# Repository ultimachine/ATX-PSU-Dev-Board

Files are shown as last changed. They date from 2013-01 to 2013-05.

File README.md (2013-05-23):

##About
This is an ATX breakout board inspired and based on <http://www.sparkfun.com/products/9558>.

##Purchasing
The board can be purchased from UltiMachine.com in PCB-only, DIY-kit, or assembled form at <https://ultimachine.com/content/atx-psu-dev-board>.

##License
This work is licensed under the [Creative Commons Attribution-ShareAlike 3.0 United States License](http://creativecommons.org/licenses/by-sa/3.0/us/).

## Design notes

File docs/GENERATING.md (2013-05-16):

#Note
This documentation procedure is very rough and still in development. The goal of the documentation for the ATX PSU Dev Board was to experiment with reducing the amount of time required for documenting in multiple places. For this project a shell script was used to quickly prototype the workflow. It is far from an ideal solution, but has given us ideas for future implementations. 

#Triple Documentation Workflow
The main content is written in markdown. A title page for the PDF is created in LaTeX. The photos are edited in GIMP. ImageMagick and xcf2png are used to convert the GIMP files to png and scale them. We use pandoc to convert the markdown to mediawiki for reprap.org (and other websites). Next the markdown is converted to LaTeX and appended to the title page. We generate a PDF from the LaTeX. All of this is performed with the build.sh script.

#Contributing
Modifications to the documentation happen in the following files/folders.

- build.sh (Build script)
- user-manual.md (Human generated instructions)
- user-manual.tex (The title page for the PDF, includes the LaTeX output from pandoc)
- /xcf (All the pictures editable in GIMP)

Everything else is generated by a piece of software and is recreated each build (for now, however an ideal solution would be like a makefile). 

##Markdown Syntax
<http://daringfireball.net/projects/markdown/syntax>

#Required Programs to run build.sh

- ImageMagick
- xcf2png
- pandoc
- pdflatex

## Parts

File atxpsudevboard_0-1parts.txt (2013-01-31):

Partlist

Exported from atxpsudevboard_0-1.sch at 1/9/2012 9:30:20 AM

EAGLE Version 6.0.0 Copyright (c) 1988-2011 CadSoft

Assembly variant: 

Part     Value /Newark No.  Device             Package           Library         Sheet

F1       5A   16F1791       PTCFUSEMFR1100     MFR1100           RepRapjr        1
F2       11A  60H8377       PTCFUSEMFR1100     MFR1100           RepRapjr        1
F3       5A   16F1791       PTCFUSEMFR1100     MFR1100           RepRapjr        1
F4       5A   16F1791       PTCFUSEMFR1100     MFR1100           RepRapjr        1
F5       5A   16F1791       PTCFUSEMFR1100     MFR1100           RepRapjr        1
H5       MOUNT-PAD-ROUND3.0 MOUNT-PAD-ROUND3.0 3,0-PAD           holes           1
H6       MOUNT-PAD-ROUND3.0 MOUNT-PAD-ROUND3.0 3,0-PAD           holes           1
H7       MOUNT-PAD-ROUND3.0 MOUNT-PAD-ROUND3.0 3,0-PAD           holes           1
H8       MOUNT-PAD-ROUND3.0 MOUNT-PAD-ROUND3.0 3,0-PAD           holes           1
J1       ATX24RH            ATX24RH            ATX24_RIGHT_ANGLE SparkFun        1
JP1                         PINHD-1X2          1X02              pinhead         1
JP2                         M06LONGPADS        1X06_LONGPADS     SparkFun        1
LED1                        LED3MM             LED3MM            led             1
LED2                        LED3MM             LED3MM            led             1
R1       30R (5W) 16R2247   RHPS923            HPS923            resistor-power  1
R2       22R (3W) 74M3349   RCA4050            CA4050            resistor-power  1
R3       1K                 R-US_0207/7        0207/7            resistor        1
R4       1K                 R-US_0207/7        0207/7            resistor        1
X2       MSTBA10            MSTBA10            MSTBA10           con-phoenix-508 1
         MSTBA pluggables for each

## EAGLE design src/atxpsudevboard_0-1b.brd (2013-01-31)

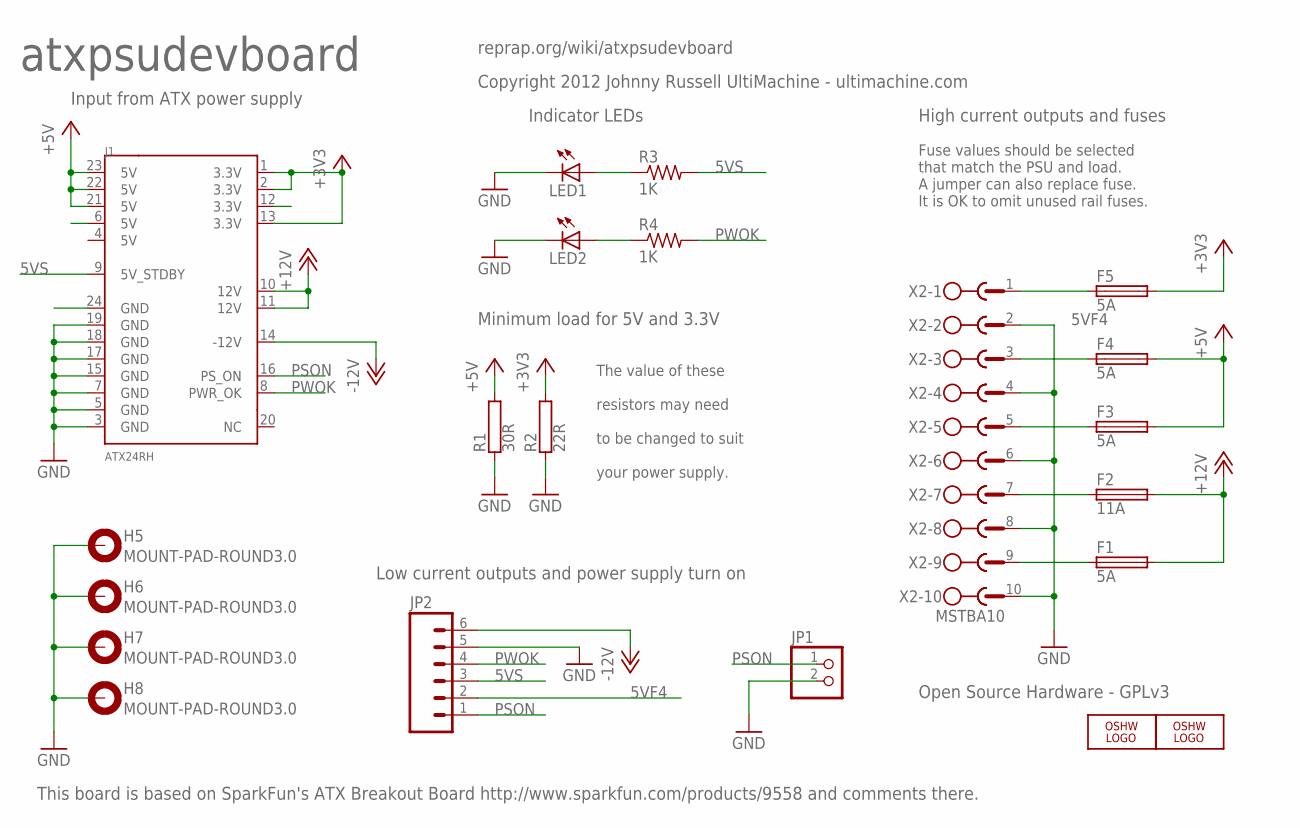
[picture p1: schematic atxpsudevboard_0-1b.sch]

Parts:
F1, F3, F4, F5: 5A; MFR1100
F2: 11A; MFR1100
H5, H6, H7, H8: MOUNT-PAD-ROUND3.0; 3,0-PAD
J1: ATX24RH; ATX24_RIGHT_ANGLE
JP1: PINHD-1X2; 1X02
JP2: M06LONGPADS; 1X06_LONGPADS
LED1, LED2: LED3MM
LOGO1: OSHW_LOGO_FILLX0100-NT; OSHW_FILLX100_NOTEXT
LOGO2: OSHW_LOGO_FILLX0200-NT; OSHW_FILLX200_NOTEXT
R1: 30R; HPS923
R2: 22R; CA4050
R3, R4: 1K; 0207/7
X2: MSTBA10

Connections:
5VF4: F4.1, JP2.2, X2.3
5VS: J1.9 (5V_STDBY), JP2.3, R3.2
+3V3: F5.2, J1.1 (3.3V), J1.2 (3.3V), J1.13 (3.3V), R2.2
+5V: F3.2, F4.2, J1.21 (5V), J1.22 (5V), J1.23 (5V), R1.2
+12V: F1.2, F2.2, J1.10 (12V), J1.11 (12V)
-12V: J1.14 (-12V), JP2.6
GND: H5.B3,0, H6.B3,0, H7.B3,0, H8.B3,0, J1.3 (GND), J1.5 (GND), J1.7 (GND), J1.15 (GND), J1.17 (GND), J1.18 (GND), J1.19 (GND), JP1.2, JP2.5, LED1.K (C), LED2.K (C), R1.1, R2.1, X2.2, X2.4, X2.6, X2.8, X2.10
unnamed: F2.1, X2.7
unnamed: F1.1, X2.9
unnamed: F3.1, X2.5
unnamed: F5.1, X2.1
unnamed: LED1.A, R3.1
unnamed: LED2.A, R4.1
PSON: J1.16 (PS_ON), JP1.1, JP2.1
PWOK: J1.8 (PWR_OK), JP2.4, R4.2

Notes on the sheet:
atxpsudevboard
Input from ATX power supply
Indicator LEDs
Minimum load for 5V and 3.3V
to be changed to suit
your power supply.
The value of these
resistors may need
Low current outputs and power supply turn on
High current outputs and fuses
Copyright 2012 Johnny Russell UltiMachine - ultimachine.com
reprap.org/wiki/atxpsudevboard
Open Source Hardware - GPLv3
This board is based on SparkFun's ATX Breakout Board http://www.sparkfun.com/products/9558 and comments there.
Fuse values should be selected
that match the PSU and load.
A jumper can also replace fuse.
It is OK to omit unused rail fuses.

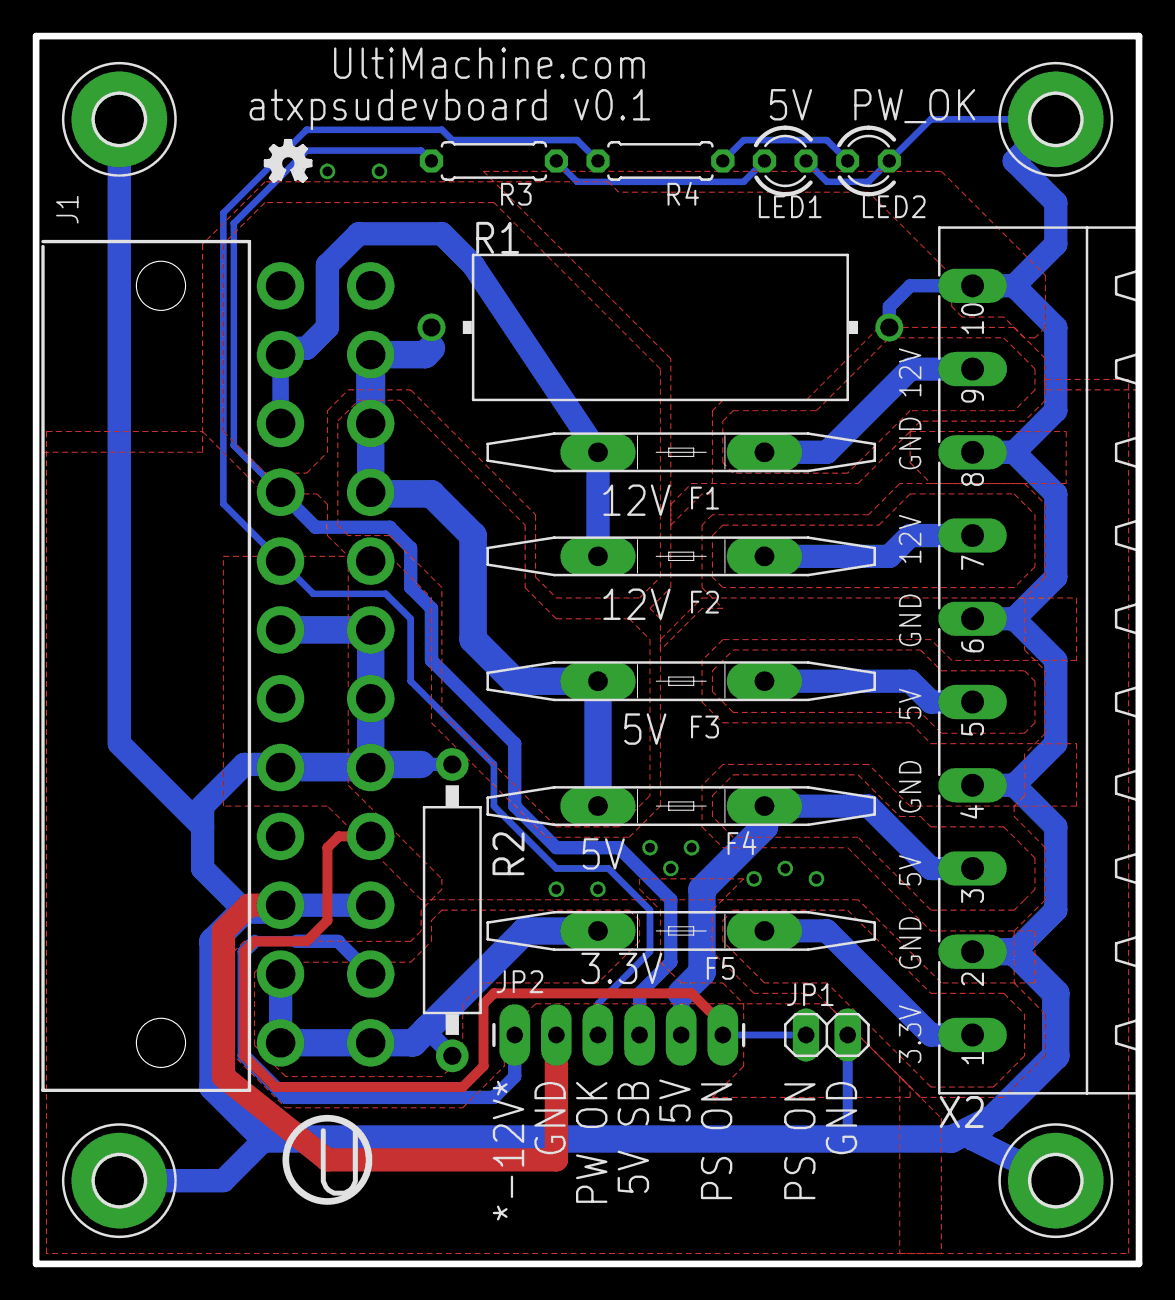
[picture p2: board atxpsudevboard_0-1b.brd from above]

Board: 2 copper layers, 67.3 x 74.9 mm, 21 parts (0 on the bottom side), 15 nets.

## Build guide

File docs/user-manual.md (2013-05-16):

#Introduction

##What's in the box
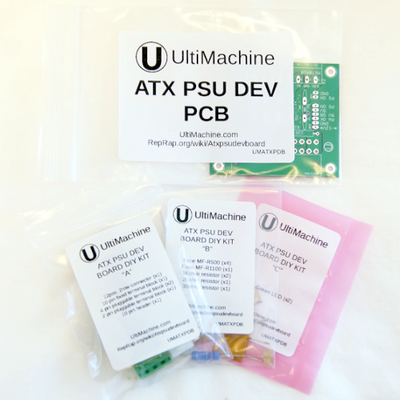
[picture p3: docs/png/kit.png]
Bag Layout


#Preparation

##Tools
The following tools and materials are required to assemble the ATX PSU Dev Board:

- Soldering Iron
- Solder
- Flush/diagonal cutters

Additional tools that might be helpful, but not required:

- Lead bender (some 3D printable ones can be found online)

##Soldering
If you do not have prior experience soldering, we recommend checking out a few of the following websites for tutorials.

- <http://mightyohm.com/files/soldercomic/FullSolderComic_EN.pdf>
- <http://www.ladyada.net/media/common/soldering.pdf>
- <http://store.curiousinventor.com/guides/How_to_Solder>
- <http://www.sparkfun.com/tutorials/106>
- <http://radiojove.gsfc.nasa.gov/telescope/soldering.htm>

#Assembly

##Board Orientation
The components of this board will be inserted on the side with the outlines.

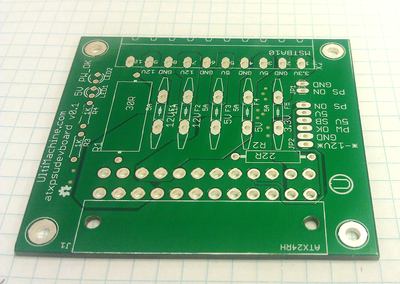
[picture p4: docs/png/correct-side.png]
Correct Side
 

##Step 1
Begin by inserting the two 1k ohm [resistors](http://en.wikipedia.org/wiki/Resistors) and the [LEDs](http://en.wikipedia.org/wiki/LED) into the board. The LEDs should have the longest lead in the hole facing the resistor. If they are inserted incorrectly they will not work. This is because they are diodes. Diodes only allow current to flow in one direction. Resistors are not [polarized](http://en.wikipedia.org/wiki/Electrical_polarity) components, so they can be inserted in orientation.

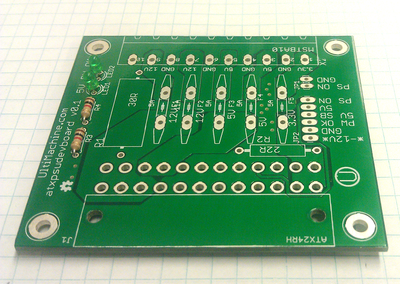
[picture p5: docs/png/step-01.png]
Step 1


##Step 2
Next flip over the board and solder the components in. You may need to slightly bend the leads to prevent the componets from falling out of the board. 

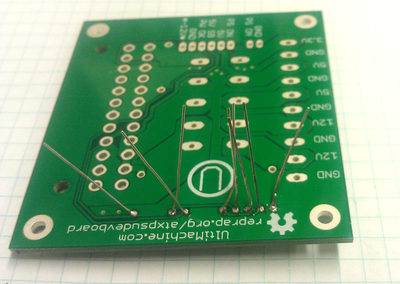
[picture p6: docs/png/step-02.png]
Step 2


##Step 3
Now that the components are soldered in and secure, you can cut the leads.

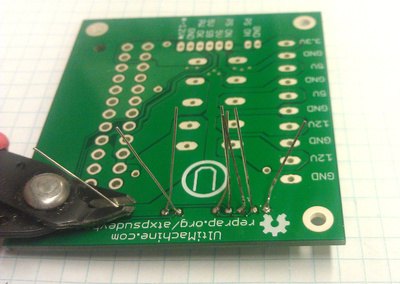
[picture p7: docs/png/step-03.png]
Step 3


##Step 4
The [fuses](http://en.wikipedia.org/wiki/Fuse_%28electrical%29) will be inserted next. They have a coating that slightly descends down the leads as shown below.

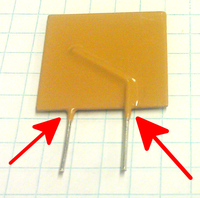
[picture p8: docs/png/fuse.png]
Resetable Fuse


In order to make a good connection the fuses should slightly hover over the holes. This is so the coating on the leads does not interfere with soldering. You want to bring the fuse above the board. This can be done with RepRap filament or something else, such as a long screw. The orientation of the fuses does not matter. 

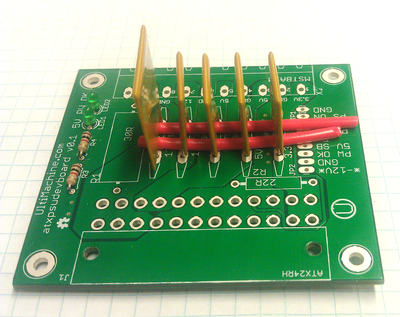
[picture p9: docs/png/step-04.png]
Step 4


##Step 5
You will need to remove the filament before continuing. 

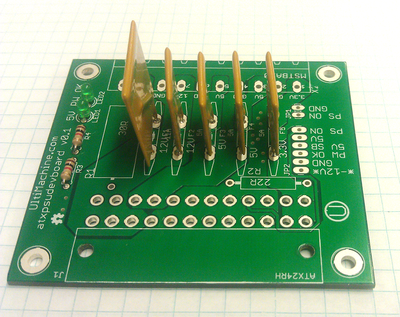
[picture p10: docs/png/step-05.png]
Step 5


Now is a good opportunity to inspect the solder joints. Since the connectors and fuses on this board might carry as much as 10 amps you want a good solder connection. You can check the quality of the solder joint by looking at the other side of the leads. A good connection is shown on the left lead, with a potentially weak one on the right lead. Add some [flux](http://en.wikipedia.org/wiki/Flux_%28metallurgy%29) and reheat the joint to touch-up the connections if needed. 

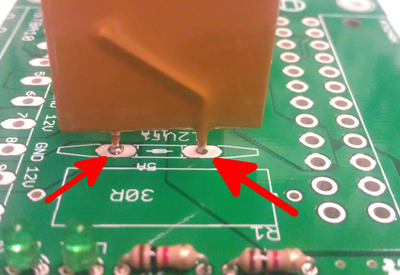
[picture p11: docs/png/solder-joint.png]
Solder Joint


##Step 6
Next you will want to solder in the remaining resistors. Again, orientation does not matter for resistors.

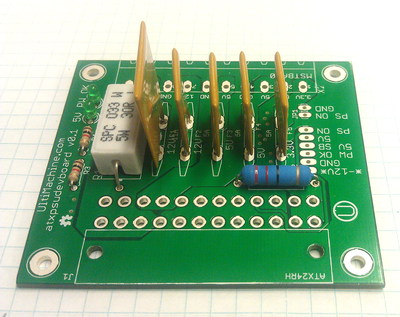
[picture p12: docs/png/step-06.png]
Step 6
 

##Header Pin Preparation
Next locate the header pins in the parts bag. You will need to break them into a strip of 6 and 2 as shown below. This can be done with flush cutters.

Split header pins 

##Step 7
Solder the header pins as shown.

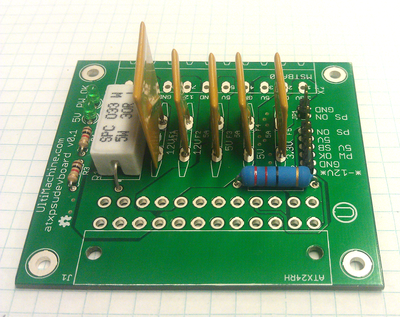
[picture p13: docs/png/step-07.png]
Step 7
 

##Step 8
Add the recieving end for the pluggable headers.

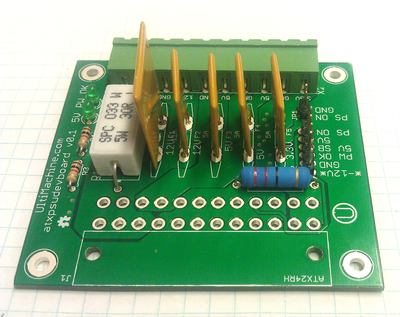
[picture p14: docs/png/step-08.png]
Step 8
 

##Step 9
Next you will want to add the ATX connector. It has barbs on the housing that should clip onto the circuit board. Make sure the connector is well seated before soldering.

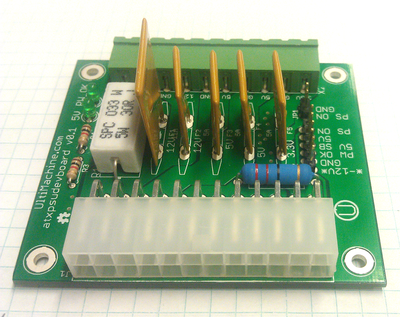
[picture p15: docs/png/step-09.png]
Step 9
 

You have now completed assembly of the ATX PSU Dev Board!
 
#Usage
In order to turn the power supply on, a jumper between "PS ON" and "GND" must be added. Optionally, this can be connected to a micro controller.

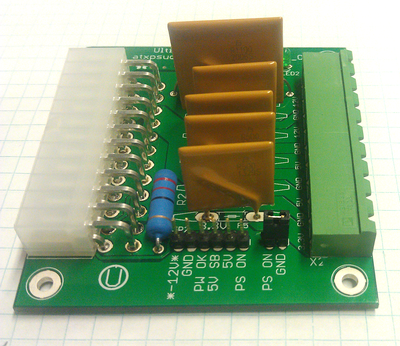
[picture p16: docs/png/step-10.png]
PS_ON Jumper
 

When an ATX power supply is connected to the board and turned on the "PW OK" and "5V" light will turn on. Otherwise if not turned on but connected, just the "5V" light will be on.

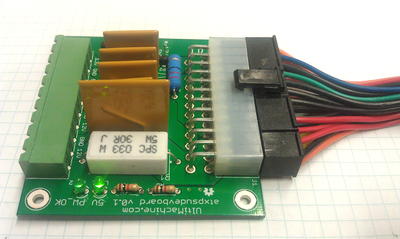
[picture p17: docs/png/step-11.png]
Testing a power supply


Finally you can connect the pluggable headers into the board and power your project!

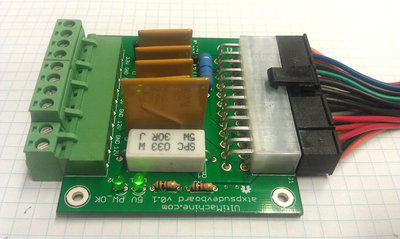
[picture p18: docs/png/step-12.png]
Pluggable headers inserted


#Source
The source for the ATX PSU Dev Board can be found in the UltiMachine repositories on GitHub.com at <https://github.com/ultimachine/ATX-PSU-Dev-Board>.

#Issues
Product support inquiries can be directed to <info@ultimachine.com>.
In the event there is an error in the documentation or problem with the board, please report the issue to the bug tracker at <https://github.com/ultimachine/ATX-PSU-Dev-Board/issues>.

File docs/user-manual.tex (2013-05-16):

\documentclass{article}

\usepackage[pdftex]{geometry}	% Use A4 paper margins
\usepackage[english]{babel}
\usepackage{graphicx}
\usepackage{url}
\usepackage{hyperref}
\usepackage{float}
\usepackage{xcolor} % Required for specifying custom colors
\usepackage{fix-cm} % Allows increasing the font size of specific fonts beyond LaTeX default specifications
\usepackage{tikz}
\usepackage{listings}
\usepackage{pgfplots}
\usepackage{float}
\usepackage{todonotes}
\usepackage{rotating}
\usepackage{pgfplotstable}

\setlength{\oddsidemargin}{0mm} % Adjust margins to center the colored title box
\setlength{\evensidemargin}{0mm} % Margins on even pages - only necessary if adding more content to this template

\newcommand{\HRule}[1]{\hfill \rule{0.2\linewidth}{#1}} % Horizontal rule at the bottom of the page, adjust width here
\renewcommand{\familydefault}{\sfdefault}
\let\ORIincludegraphics\includegraphics
\renewcommand{\includegraphics}[2][]{\ORIincludegraphics[scale=0.7,#1]{#2}}
\begin{document}

\begin{titlepage}

  {\Huge ATX PSU Dev Board }\\
  {\Large Assembly Instructions for v0.1} 
  \vspace*{\fill}	
  \begin{center}
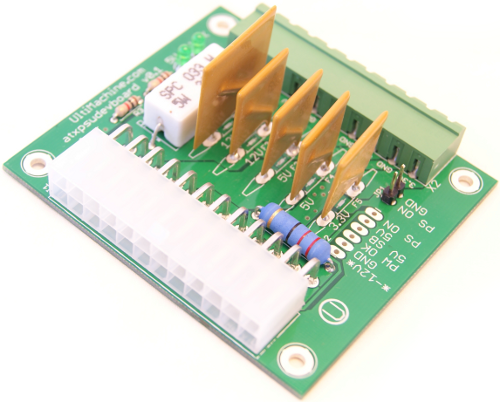
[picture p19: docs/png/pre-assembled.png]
  
  \end{center}
  \vspace*{\fill}

  \vfill
  {\centering \large 
  \hfill  \\
  \hfill \url{http://ultimachine.com/content/atx-psu-dev-board} \\

  \HRule{1pt}} % Horizontal line, thickness changed here
\end{titlepage}

\clearpage % Whitespace to the end of the page

\tableofcontents
\clearpage

\input{./tex/user-manual-body.tex}

\end{document}

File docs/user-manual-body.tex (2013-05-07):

\section{Overview}

\subsection{Introduction}

\subsubsection{What's in the box}

\begin{figure}[htbp]
\centering

\caption{Bag Layout}
\end{figure}

\subsection{Assembly}

\subsubsection{Preparation}

\paragraph{Tools}

The following tools and materials are required to assemble the ATX PSU
Dev Board:

\begin{itemize}
\itemsep1pt\parskip0pt\parsep0pt
\item
  Soldering Iron
\item
  Solder
\item
  Flush/diagonal cutters
\end{itemize}

Additional tools that might be helpful, but not required:

\begin{itemize}
\itemsep1pt\parskip0pt\parsep0pt
\item
  Lead bender (some 3D printable ones can be found online)
\end{itemize}

\paragraph{Soldering}

If you do not have prior experience soldering, we recommend checking out
a few of the following websites for tutorials.

\begin{itemize}
\itemsep1pt\parskip0pt\parsep0pt
\item
  \url{http://mightyohm.com/files/soldercomic/FullSolderComic_EN.pdf}
\item
  \url{http://www.ladyada.net/media/common/soldering.pdf}
\item
  \url{http://store.curiousinventor.com/guides/How_to_Solder}
\item
  \url{http://www.sparkfun.com/tutorials/106}
\item
  \url{http://radiojove.gsfc.nasa.gov/telescope/soldering.htm}
\end{itemize}

\subsubsection{Assembly}

The components of this board will be inserted on the side with the
outlines

\begin{figure}[htbp]
\centering
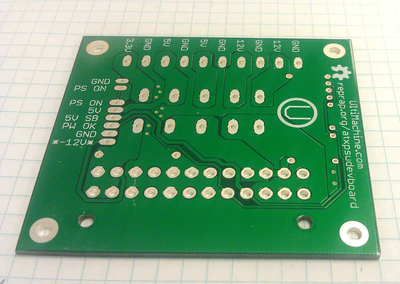
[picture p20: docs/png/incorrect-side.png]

\caption{Incorrect Side}
\end{figure}

Begin by inserting the two 1k ohm resistors and the LEDs into the board.
The LEDs should have the longest lead in the hole facing the resistor.
If they are inserted incorrectly they will not work. This is because
they are diodes. Resistors are not polarized components, so they can be
inserted in orientation.

\begin{figure}[htbp]
\centering

\caption{Step 1}
\end{figure}

Next flip over the board and solder the components in.

\begin{figure}[htbp]
\centering

\caption{Step 2}
\end{figure}

Now that the components are soldered in and secure you can cut the
leads.

\begin{figure}[htbp]
\centering

\caption{Step 3}
\end{figure}

The fuses will be inserted next. They have a coating that slightly
descends down the leads.

\begin{figure}[htbp]
\centering

\caption{Resetable Fuse}
\end{figure}

In order to make a good connection the fuses should slightly hover over
the holes. This is so the coating on the leads does not interfere with
soldering. You want to bring the fuse above the board. This can be done
with RepRap filament or something else, such as a long screw. The
orientation of the fuses does not matter.

\begin{figure}[htbp]
\centering

\caption{Step 4}
\end{figure}

You can remove the filament.

\begin{figure}[htbp]
\centering

\caption{Step 5}
\end{figure}

Now is a good opportunity to check that all connections were soldered
well. Ideally the solder should wick up the lead onto the other side of
the board. It should also have a nice tapered look. Add some flux and
reheat the joint to touch-up the connections if needed. \textbackslash{}

Now is a good opportunity to inspect the solder joints. Since the
connectors and fuses on this board might carry as much as 10 amps you
want a good solder connection. You can check the quality of the solder
joint by looking at the other side of the leads. A good connection is
shown on the left lead, with a potentially weak one on the right lead.

\begin{figure}[htbp]
\centering

\caption{Solder Joint}
\end{figure}

Next you will want to solder in the remaining resistors. Again,
orientation does not matter for resistors.

\begin{figure}[htbp]
\centering

\caption{Step 6}
\end{figure}

Next locate the header pins in the parts bag. You will need to break
them into a strip of 6 and 2 as shown below. This can be done with flush
cutters.

\begin{figure}[htbp]
\centering

\caption{Split header pins}
\end{figure}

Solder the header pins as shown.

\begin{figure}[htbp]
\centering

\caption{Step 7}
\end{figure}

Add the recieving end for the pluggable headers.

\begin{figure}[htbp]
\centering

\caption{Step 8}
\end{figure}

Next you will want to add the ATX connector. It has barbs on the housing
that should clip onto the circuit board. Make sure the connector is well
seated before soldering.

\begin{figure}[htbp]
\centering

\caption{Step 9}
\end{figure}

You have now completed assembly of the ATX PSU Dev Board!

\section{Usage}

\begin{figure}[htbp]
\centering

\caption{PS\_ON Jumper}
\end{figure}

\begin{figure}[htbp]
\centering

\caption{Testing a power supply}
\end{figure}

\begin{figure}[htbp]
\centering

\caption{Pluggable headers inserted}
\end{figure}

\section{Source}

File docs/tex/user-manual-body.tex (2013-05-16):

\section{Introduction}

\subsection{What's in the box}

\begin{figure}[H]
\centering

\caption{Bag Layout}
\end{figure}

\section{Preparation}

\subsection{Tools}

The following tools and materials are required to assemble the ATX PSU
Dev Board:

\begin{itemize}
\itemsep1pt\parskip0pt\parsep0pt
\item
  Soldering Iron
\item
  Solder
\item
  Flush/diagonal cutters
\end{itemize}

Additional tools that might be helpful, but not required:

\begin{itemize}
\itemsep1pt\parskip0pt\parsep0pt
\item
  Lead bender (some 3D printable ones can be found online)
\end{itemize}

\subsection{Soldering}

If you do not have prior experience soldering, we recommend checking out
a few of the following websites for tutorials.

\begin{itemize}
\itemsep1pt\parskip0pt\parsep0pt
\item
  \url{http://mightyohm.com/files/soldercomic/FullSolderComic_EN.pdf}
\item
  \url{http://www.ladyada.net/media/common/soldering.pdf}
\item
  \url{http://store.curiousinventor.com/guides/How_to_Solder}
\item
  \url{http://www.sparkfun.com/tutorials/106}
\item
  \url{http://radiojove.gsfc.nasa.gov/telescope/soldering.htm}
\end{itemize}

\section{Assembly}

\subsection{Board Orientation}

The components of this board will be inserted on the side with the
outlines.

\begin{figure}[H]
\centering

\caption{Correct Side}
\end{figure}

\subsection{Step 1}

Begin by inserting the two 1k ohm
\href{http://en.wikipedia.org/wiki/Resistors}{resistors} and the
\href{http://en.wikipedia.org/wiki/LED}{LEDs} into the board. The LEDs
should have the longest lead in the hole facing the resistor. If they
are inserted incorrectly they will not work. This is because they are
diodes. Diodes only allow current to flow in one direction. Resistors
are not
\href{http://en.wikipedia.org/wiki/Electrical_polarity}{polarized}
components, so they can be inserted in orientation.

\begin{figure}[H]
\centering

\caption{Step 1}
\end{figure}

\subsection{Step 2}

Next flip over the board and solder the components in. You may need to
slightly bend the leads to prevent the componets from falling out of the
board.

\begin{figure}[H]
\centering

\caption{Step 2}
\end{figure}

\subsection{Step 3}

Now that the components are soldered in and secure, you can cut the
leads.

\begin{figure}[H]
\centering

\caption{Step 3}
\end{figure}

\subsection{Step 4}

The \href{http://en.wikipedia.org/wiki/Fuse_\%28electrical\%29}{fuses}
will be inserted next. They have a coating that slightly descends down
the leads as shown below.

\begin{figure}[H]
\centering

\caption{Resetable Fuse}
\end{figure}

In order to make a good connection the fuses should slightly hover over
the holes. This is so the coating on the leads does not interfere with
soldering. You want to bring the fuse above the board. This can be done
with RepRap filament or something else, such as a long screw. The
orientation of the fuses does not matter.

\begin{figure}[H]
\centering

\caption{Step 4}
\end{figure}

\subsection{Step 5}

You will need to remove the filament before continuing.

\begin{figure}[H]
\centering

\caption{Step 5}
\end{figure}

Now is a good opportunity to inspect the solder joints. Since the
connectors and fuses on this board might carry as much as 10 amps you
want a good solder connection. You can check the quality of the solder
joint by looking at the other side of the leads. A good connection is
shown on the left lead, with a potentially weak one on the right lead.
Add some
\href{http://en.wikipedia.org/wiki/Flux_\%28metallurgy\%29}{flux} and
reheat the joint to touch-up the connections if needed.

\begin{figure}[H]
\centering

\caption{Solder Joint}
\end{figure}

\subsection{Step 6}

Next you will want to solder in the remaining resistors. Again,
orientation does not matter for resistors.

\begin{figure}[H]
\centering

\caption{Step 6}
\end{figure}

\subsection{Header Pin Preparation}

Next locate the header pins in the parts bag. You will need to break
them into a strip of 6 and 2 as shown below. This can be done with flush
cutters.

\begin{figure}[H]
\centering

\caption{Split header pins}
\end{figure}

\subsection{Step 7}

Solder the header pins as shown.

\begin{figure}[H]
\centering

\caption{Step 7}
\end{figure}

\subsection{Step 8}

Add the recieving end for the pluggable headers.

\begin{figure}[H]
\centering

\caption{Step 8}
\end{figure}

\subsection{Step 9}

Next you will want to add the ATX connector. It has barbs on the housing
that should clip onto the circuit board. Make sure the connector is well
seated before soldering.

\begin{figure}[H]
\centering

\caption{Step 9}
\end{figure}

You have now completed assembly of the ATX PSU Dev Board!

\section{Usage}

In order to turn the power supply on, a jumper between ``PS ON'' and
``GND'' must be added. Optionally, this can be connected to a micro
controller.

\begin{figure}[H]
\centering

\caption{PS\_ON Jumper}
\end{figure}

When an ATX power supply is connected to the board and turned on the
``PW OK'' and ``5V'' light will turn on. Otherwise if not turned on but
connected, just the ``5V'' light will be on.

\begin{figure}[H]
\centering

\caption{Testing a power supply}
\end{figure}

Finally you can connect the pluggable headers into the board and power
your project!

\begin{figure}[H]
\centering

\caption{Pluggable headers inserted}
\end{figure}

\section{Source}

The source for the ATX PSU Dev Board can be found in the UltiMachine
repositories on GitHub.com at
\url{https://github.com/ultimachine/ATX-PSU-Dev-Board}.

\section{Issues}

Product support inquiries can be directed to
\href{mailto:info@ultimachine.com}{info@ultimachine.com}. In the event
there is an error in the documentation or problem with the board, please
report the issue to the bug tracker at
\url{https://github.com/ultimachine/ATX-PSU-Dev-Board/issues}.

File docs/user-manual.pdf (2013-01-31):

# ATX PSU Dev Board

## Assembly Instructions for v0.1

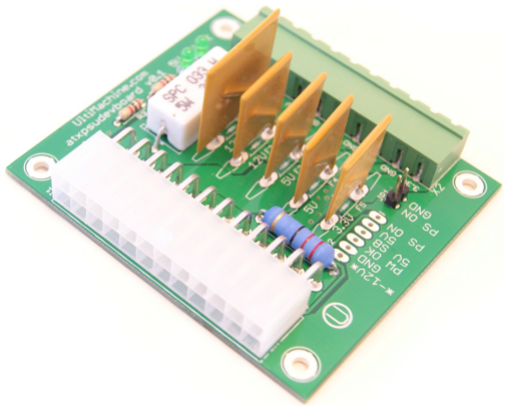
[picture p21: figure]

http://ultimachine.com/content/atx-psu-dev-board

## Contents

1 Usage | 4

1

### 0.1 Overview

### 0.1.1 Introduction

### 0.1.2 What’s in the box

### 0.2 Assembly

### 0.2.1 Preparation

Tools The following tools and materials are required to assemble the ATX PSU Dev Board:

- Soldering Iron
- Solder
- Flush/diagonal cutters

Additional tools that might be helpful, but not required:

- Lead bender

Soldering If you do not have prior experience soldering, we recommend checking out a few of the following websites for some tutorials.

- http://mightyohm.com/files/soldercomic/FullSolderComic_EN.pdf
- http://www.ladyada.net/media/common/soldering.pdf
- http://store.curiousinventor.com/guides/How_to_Solder
- http://www.sparkfun.com/tutorials/106
- http://radiojove.gsfc.nasa.gov/telescope/soldering.htm

### 0.2.2 Assembly

The components of this board will be inserted on the side with the outlines
Begin by inserting the two 1kΩ resistors and the LEDs into the board. The LEDs should have the longest lead in the hole facing the resistor. If they are inserted incorrectly they will not work. Resistors are not polarized components, so they can be inserted in orientation. \
Next flip over the board and solder the components in. \
The fuses will be inserted next. They have a coating that slightly descends down the leads. \
In order to make a good connection the fuses should slightly hover over the holes. This is so the coating on the leads does not interfere with soldering. You want to bring the fuse above the board. You can do this with RepRap filament or something else, such as a long screw. The orientation of the fuses does not matter.
Next you will want to solder in the remaining resistors. Again, orientation does not matter for resistors.
Now is a good opportunity to check that all connections were soldered well. Ideally the solder should wick up the lead onto the other side of the board. It should also have a nice tapered look. Add some flux and reheat the joint to touch-up the connections if needed. \
Next you will want to add the ATX connector. It has barbs on the housing that should clip onto the circuit board.

2

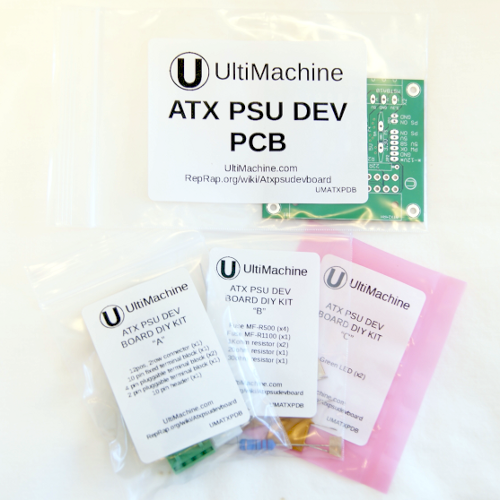
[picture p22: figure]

Figure 1: Bag Layout

3

## 1 Usage

### 1.1 Source

4
